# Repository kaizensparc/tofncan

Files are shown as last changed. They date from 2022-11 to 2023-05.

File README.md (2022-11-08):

# tofncan

## Directory Outline
- [`~/pcb/`](pcb) PCB project.
    - [`~/pcb/.kibot`](pcb/.kibot) KiBot configuration files.
    - [`~/pcb/3d_models`](pcb/3d_models) .STEP and .WRL model files for all project specific footprints.
    - [`~/pcb/datasheets`](pcb/datasheets) Data sheets for components used.
    - [`~/pcb/lib_fp.pretty`](pcb/lib_fp.pretty) Project specific footprint library.
    - [`~/pcb/kicad_project`](pcb/kicad_project) Kicad project. When starting a new KiCAD project in this directory, be sure to uncheck *Create a new directory for the project* in the **Create New Project** window.
    - [`~/pcb/lib_sch`](pcb/lib_sch) Project specific schematic symbol libraries.
        - [`~/pcb/lib_sch/lib.lib`](pcb/lib_sch/lib.lib) Project specific schematic symbol library.
    - [`~/pcb/page_layouts`](pcb/page_layouts) Page layouts for pdf outputs.
    - [`~/pcb/outputs`](pcb/outputs) Project output files generated by KiCad and/or KiBot (these are not kept under version control).
        - [`~/pcb/outputs/3d_models`](pcb/outputs/3d_models) Exported 3D models of the board.
        - [`~/pcb/outputs/assembly`](pcb/outputs/assembly) Exported assembly files.
        - [`~/pcb/outputs/bom`](pcb/outputs/bom) Exported BOM files.
        - [`~/pcb/outputs/fabrication`](pcb/outputs/fabrication) Exported production (gerber) files.
        - [`~/pcb/outputs/images`](pcb/outputs/images) Exported images and 3D board renders.
        - [`~/pcb/outputs/pdf`](pcb/outputs/pdf) Exported schematics, board layouts, dimension drawings.
- [`~/firmware/`](firmware) Firmware souce code and binaries.
- [`~/enclosure/`](enclosure) Mechanical CAD design files for the encloser or box. Create seperate directories for `.stl` or other files for 3d printing for easy accesss.

## Managing Schematic Libraries
Project specific symbols can be saved in [`~/pcb/lib_sch/lib.lib`](pcb/lib_sch/lib.lib). Link this library as a project specific library to the project **using a relative path** like `${KIPRJMOD}/../lib_sch/lib.lib`.

### Saving a copy of the global symbols.
The global symbols are pulled from Github when the repository is cloned, and this can cause problems if the global symbols have changed in the meantime. To prevent this, KiCad automatically creates a backup in the project folder of the symbols currently in use named `<<PROJECT NAME>>-cache.lib`. 

To make sure everyone uses the same, you can convert the backup of the symbol library to a symbol library. To do this you need to move this file to  [`~/pcb/lib_sch`](pcb/lib_sch) and rename it to `<<PROJECT NAME>>.lib`. After this, you can add this symbol library as a project-specific symbol library and replace all symbols with the symbols from this library. **NOTE: Do this only after you've completed your whole schematic design!**

## Managing Footprints
Project specific footprints can be saved in [`~/pcb/lib_fp/lib_fp.pretty`](pcb/lib_fp/lib_fp.pretty). Link this library as a project specific library to the project **using a relative path** like `${KIPRJMOD}/../lib_fp/lib_fp.pretty`. Global symbols that are used can be copied to this folder and replaced with this local variant. 

## Managing 3D models of components
3D models for project specific components should be saved in [`~/pcb/3d_models`](pcb/3d_models). Then they can be linked to the matching footprint **using a relative path** like `${KIPRJMOD}/../3d_models/filename.step`.

## Managing the BOM information
Add the following field name templates in Eeschema (`preferences >> Preferences... >> Field Name Templates`):

| Name | Visible | URL | _Description_ |
|:--- | :---: | :---: | :--- |
| `MFN` | :white_check_mark: | :white_large_square: | _Manufacturer name._ |
| `MFP` | :white_check_mark: | :white_large_square: | _Manufacturer product number._ |
| `LCSC#`  | :white_check_mark: | :white_large_square: | _LCSC/JLCPCB part number (leave part number empty if not using JLCPCB assembly)._ |
| `Config` | :white_check_mark: | :white_large_square: | _Board configuration to apply this part to or `DNF` if part should not be fitted on final board._ |

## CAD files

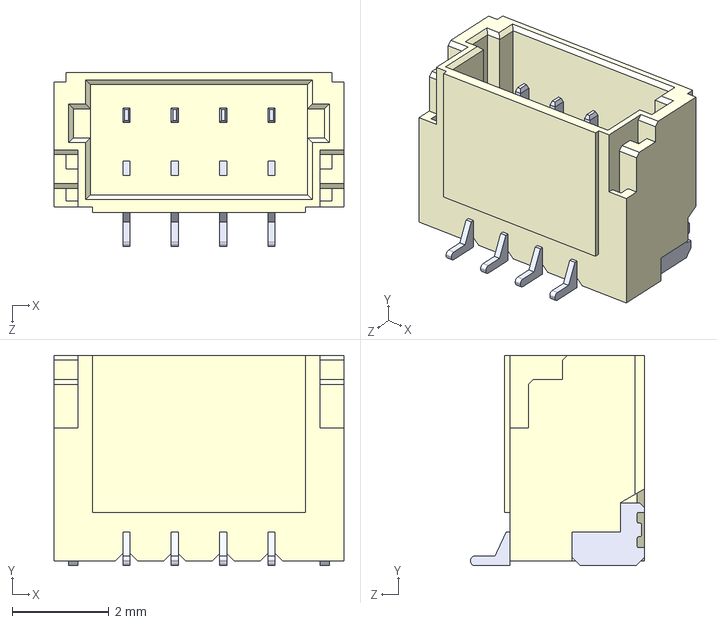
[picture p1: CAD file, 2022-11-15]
pcb/3d_models/BM04B-SRSS-TB-LF-SN.step
6.00 x 4.35 x 3.60 mm

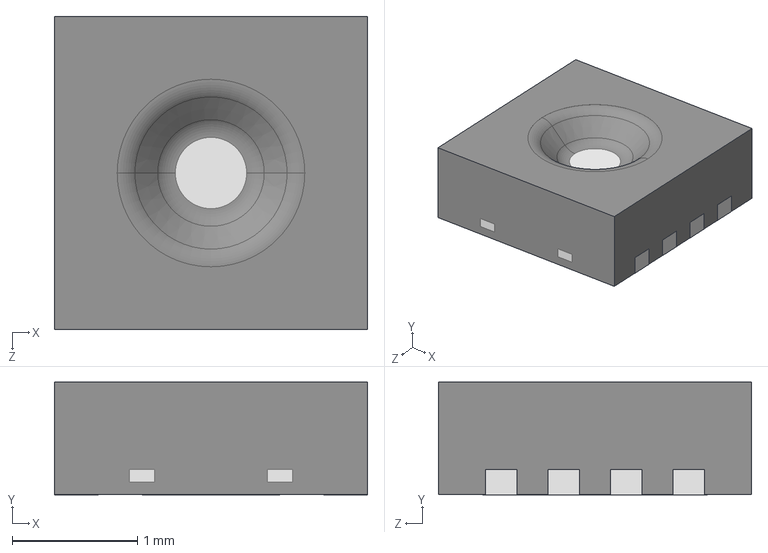
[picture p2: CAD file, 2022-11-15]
pcb/3d_models/SHT30-DIS-B.step
2.50 x 0.901 x 2.50 mm

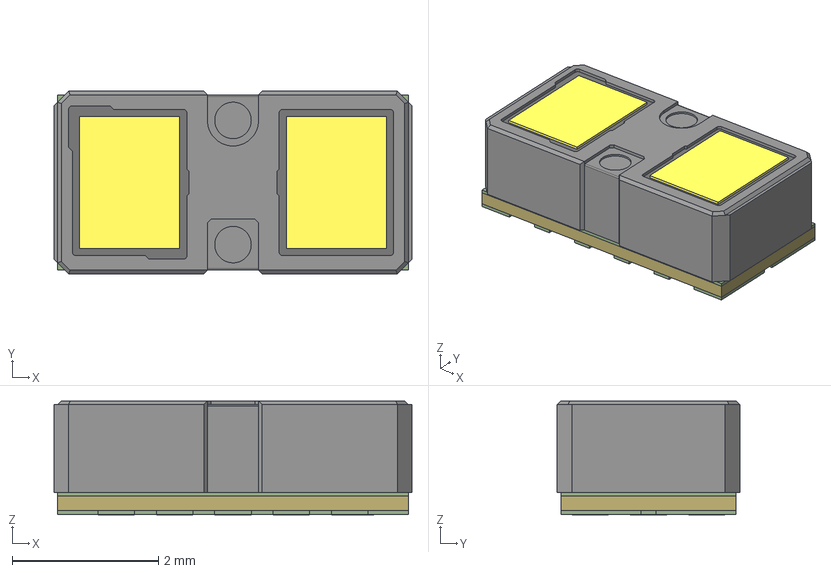
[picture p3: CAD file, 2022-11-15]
pcb/3d_models/vl53l1x.step
4.90 x 2.50 x 1.56 mm
pcb
kork
pads
blend
lens
main
blocker

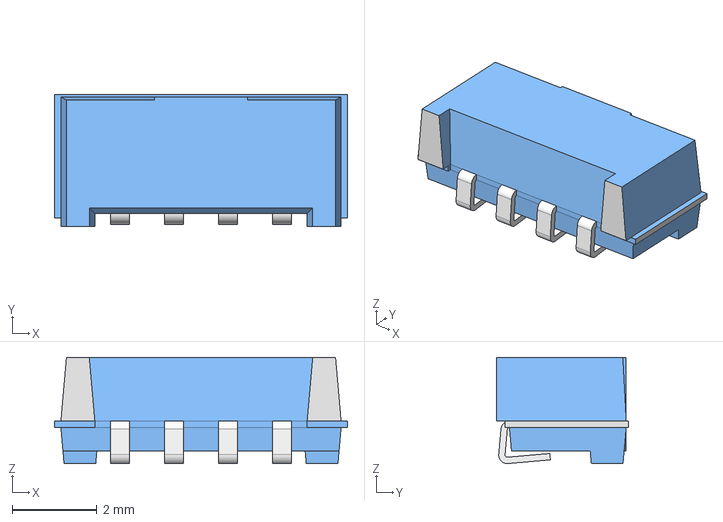
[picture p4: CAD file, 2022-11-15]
pcb/3d_models/84592VEML7700.stp
6.90 x 3.10 x 2.50 mm

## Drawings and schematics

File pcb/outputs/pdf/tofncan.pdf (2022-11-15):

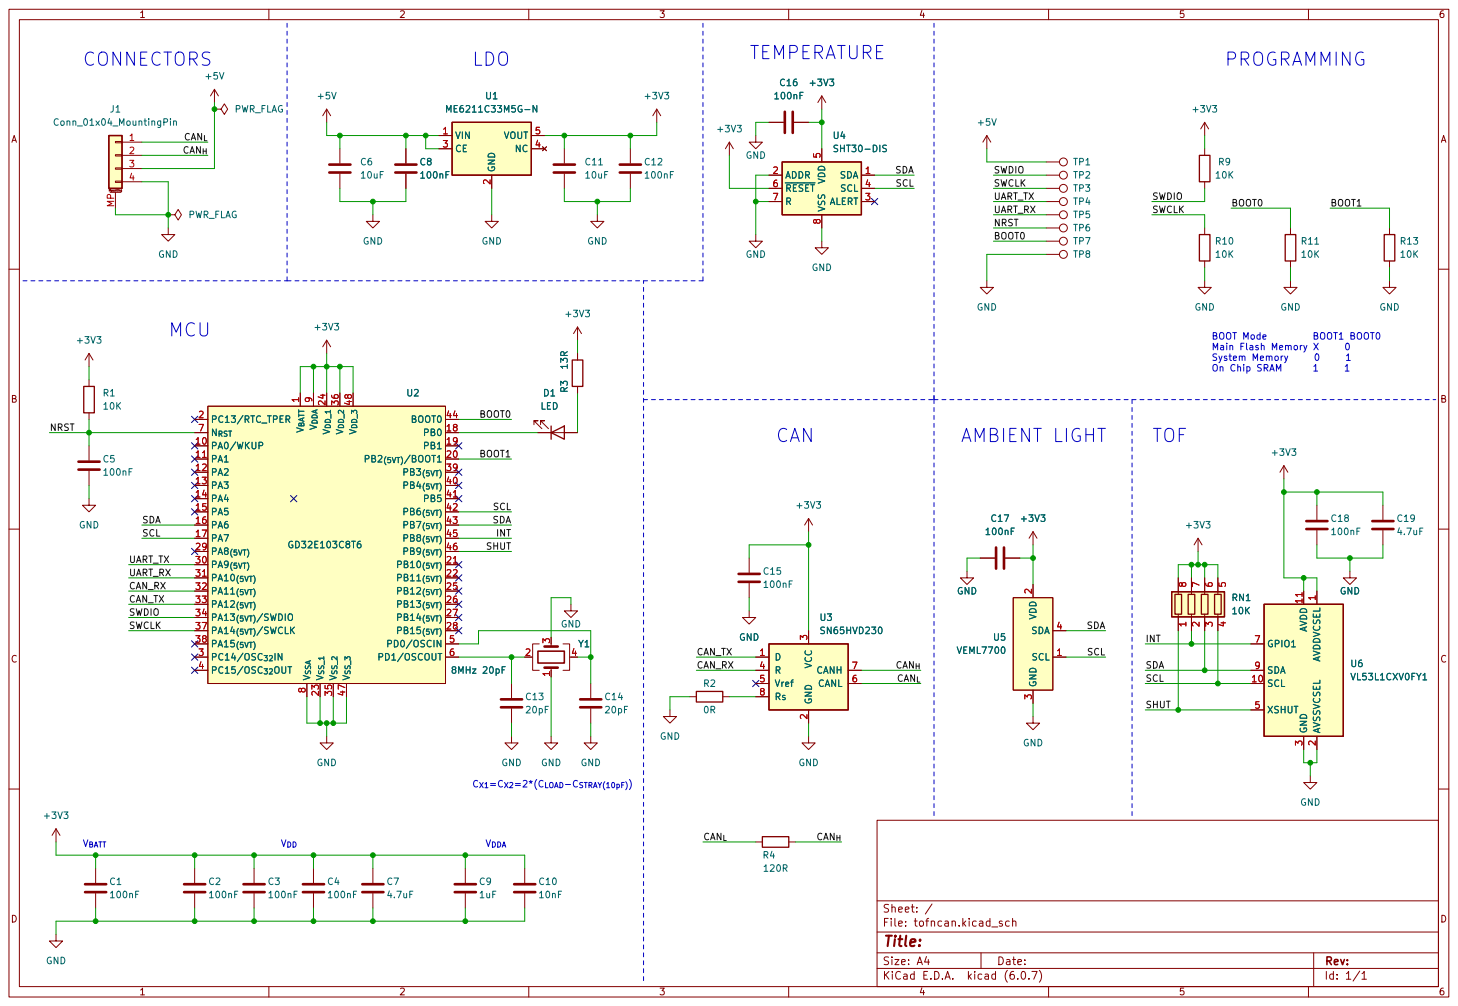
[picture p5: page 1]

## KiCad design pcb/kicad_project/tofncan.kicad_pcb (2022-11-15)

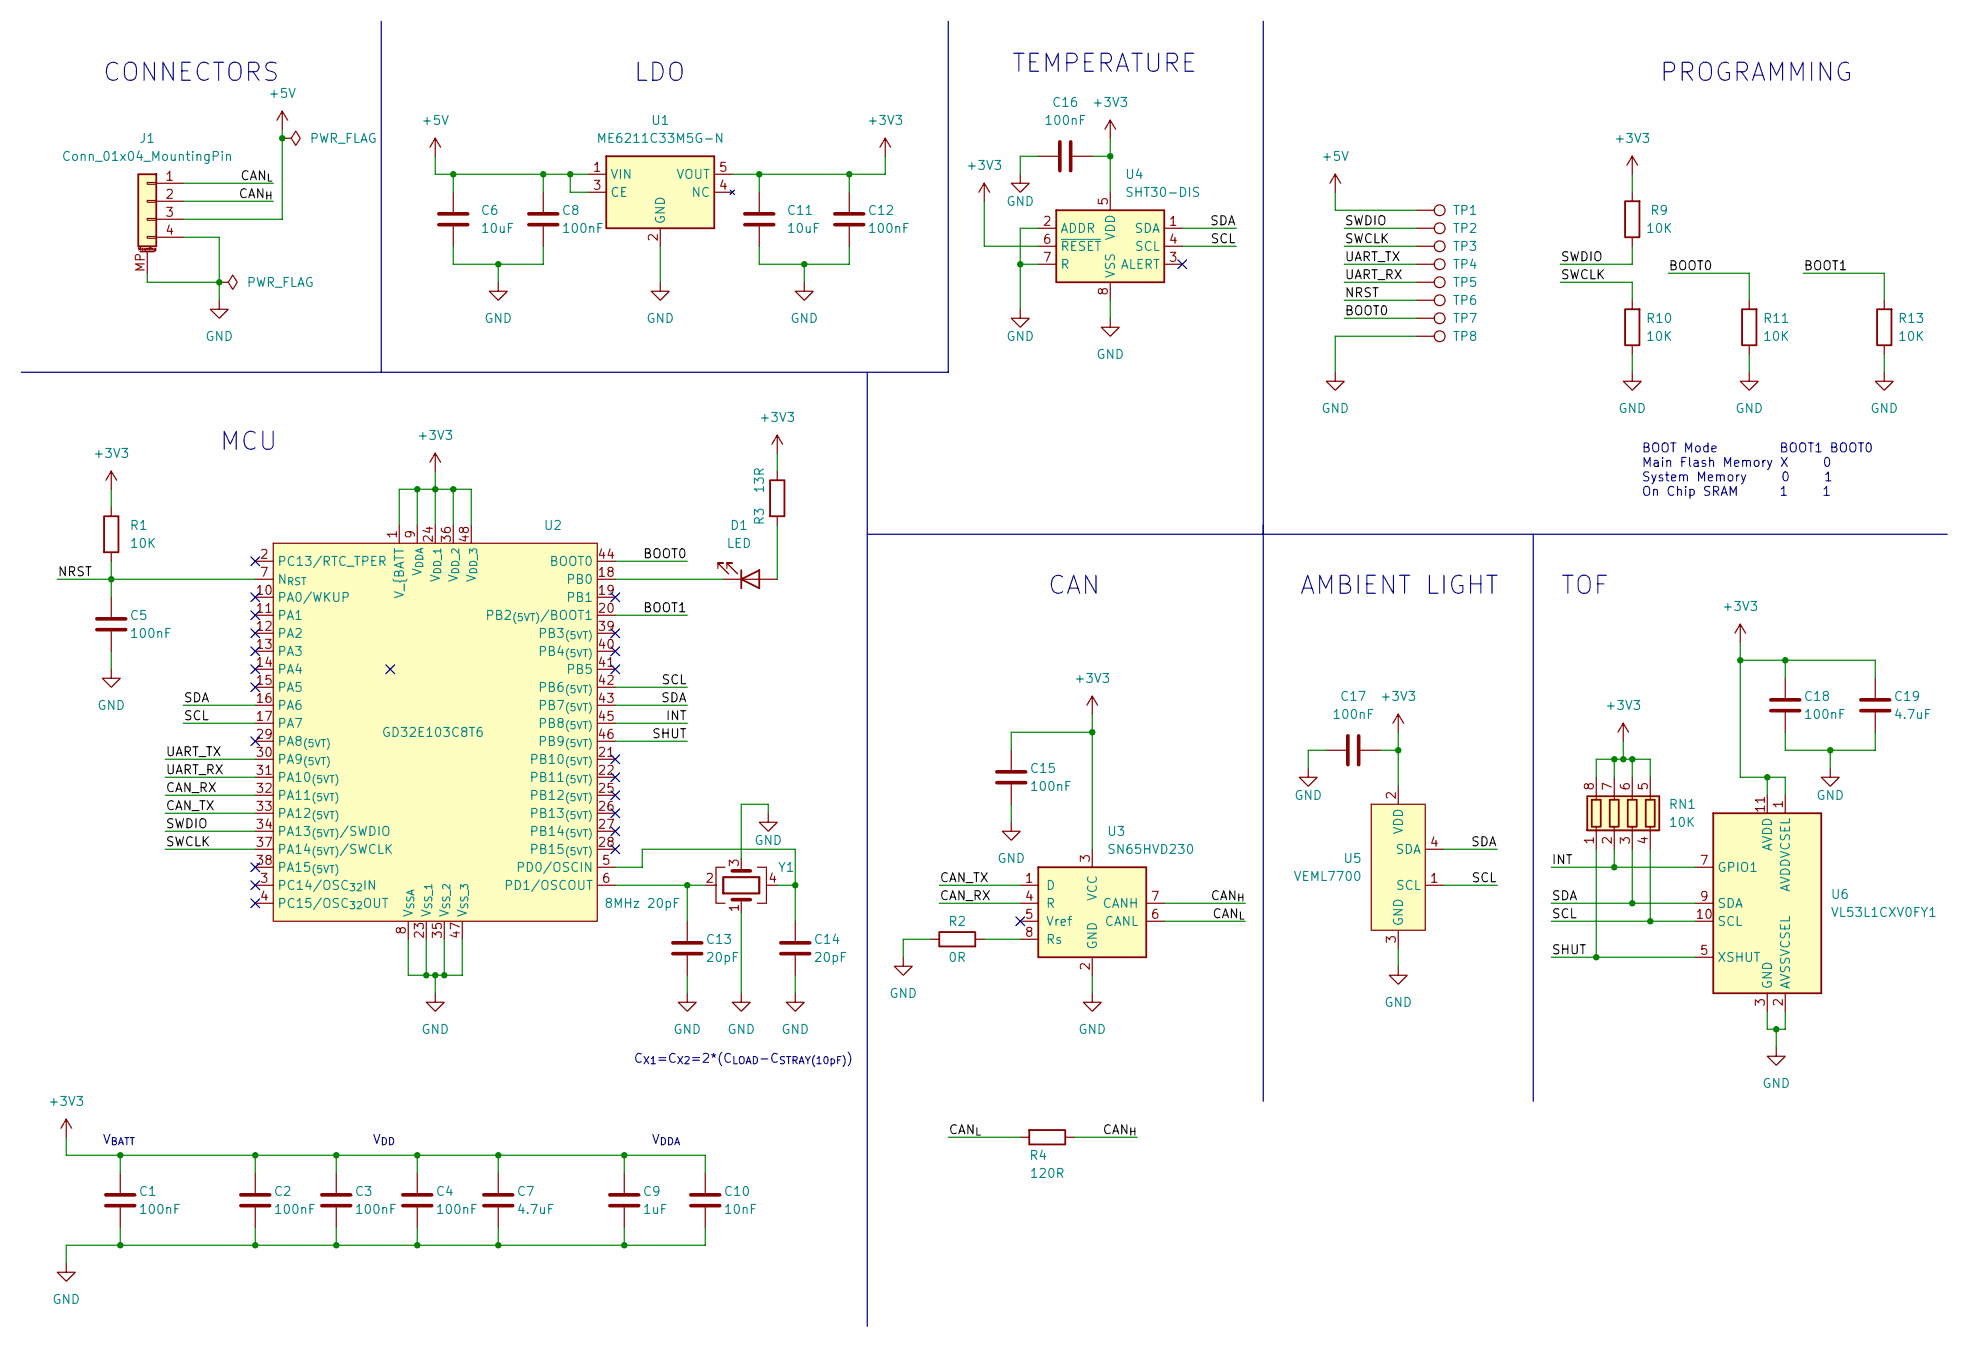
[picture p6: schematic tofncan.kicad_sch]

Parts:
C1, C2, C3, C4, C5, C8, C12, C15, C16, C17, C18: 100nF; C_0402_1005Metric; LCSC C1525
C6, C11: 10uF; C_0805_2012Metric; LCSC C88484
C7, C19: 4.7uF; C_0402_1005Metric; LCSC C23733
C9: 1uF; C_0402_1005Metric; LCSC C52923
C10: 10nF; C_0402_1005Metric; LCSC C400948
C13, C14: 20pF; C_0402_1005Metric; LCSC C76959
D1: LED; LED_0603_1608Metric; LCSC C965809
J1: Conn_01x04_MountingPin; JST_SH_BM04B-SRSS-TB_1x04-1MP_P1.00mm_Vertical; LCSC C160390
R1, R9, R10, R11, R13: 10K; R_0402_1005Metric; LCSC C60490
R2: 0R; R_0402_1005Metric; LCSC C106231
R3: 13R; R_0402_1005Metric; LCSC C412909
R4: 120R; R_0402_1005Metric; LCSC C114758
RN1: 10K; R_Array_Convex_4x0402; LCSC C326872
TP1, TP2, TP3, TP4, TP5, TP6, TP7, TP8: TestPoint; TestPoint_Pad_D1.0mm
U1: ME6211C33M5G-N; SOT-23-5; LCSC C82942
U2: GD32E103C8T6; LQFP-48_7x7mm_P0.5mm; LCSC C350804
U3: SN65HVD230; SOIC-8_3.9x4.9mm_P1.27mm; LCSC C12084
U4: SHT30-DIS; Sensirion_DFN-8-1EP_2.5x2.5mm_P0.5mm_EP1.1x1.7mm; LCSC C77361
U5: VEML7700; VEML7700-TOP; LCSC C504893
U6: VL53L1CXV0FY1; ST_VL53L1X; LCSC C190004
Y1: 8MHz 20pF; Crystal_SMD_3225-4Pin_3.2x2.5mm; LCSC C720915

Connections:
+3V3: C1.1, C2.1, C3.1, C4.1, C7.1, C9.1, C10.1, C11.1, C12.1, C15.1, C16.2, C17.2, C18.1, C19.1, R1.1, R3.1, R9.2, RN1.5 (R4.2), RN1.6 (R3.2), RN1.7 (R2.2), RN1.8 (R1.2), U1.5 (VOUT), U2.1 (V_{BATT), U2.9 (V_{DDA}), U2.24 (V_{DD_1}), U2.36 (V_{DD_2}), U2.48 (V_{DD_3}), U3.3 (VCC), U4.5 (VDD), U4.6 (~RESET), U5.2 (VDD), U6.1 (AVDDVCSEL), U6.11 (AVDD)
+5V: C6.1, C8.1, J1.3, TP1.1, U1.1 (VIN), U1.3 (CE)
/BOOT0: R11.2, TP7.1, U2.44 (BOOT0)
/BOOT1: R13.2, U2.20 (PB2_{(5VT)}/BOOT1)
/CAN_RX: U2.32 (PA11_{(5VT)}), U3.4 (R)
/CAN_TX: U2.33 (PA12_{(5VT)}), U3.1 (D)
/CAN_{H}: J1.2, R4.1, U3.7 (CANH)
/CAN_{L}: J1.1, R4.2, U3.6 (CANL)
/INT: RN1.2 (R2.1), U2.45 (PB8_{(5VT)}), U6.7 (GPIO1)
/NRST: C5.1, R1.2, TP6.1, U2.7 (N_{RST})
/SCL: RN1.4 (R4.1), U2.17 (PA7), U2.42 (PB6_{(5VT)}), U4.4 (SCL), U5.1 (SCL), U6.10 (SCL)
/SDA: RN1.3 (R3.1), U2.16 (PA6), U2.43 (PB7_{(5VT)}), U4.1 (SDA), U5.4 (SDA), U6.9 (SDA)
/SHUT: RN1.1 (R1.1), U2.46 (PB9_{(5VT)}), U6.5 (XSHUT)
/SWCLK: R10.2, TP3.1, U2.37 (PA14_{(5VT)}/SWCLK)
/SWDIO: R9.1, TP2.1, U2.34 (PA13_{(5VT)}/SWDIO)
/UART_RX: TP5.1, U2.31 (PA10_{(5VT)})
/UART_TX: TP4.1, U2.30 (PA9_{(5VT)})
GND: C1.2, C2.2, C3.2, C4.2, C5.2, C6.2, C7.2, C8.2, C9.2, C10.2, C11.2, C12.2, C13.2, C14.2, C15.2, C16.1, C17.1, C18.2, C19.2, J1.4, J1.MP (MountPin), R2.1, R10.1, R11.1, R13.1, TP8.1, U1.2 (GND), U2.8 (V_{SSA}), U2.23 (V_{SS_1}), U2.35 (V_{SS_2}), U2.47 (V_{SS_3}), U3.2 (GND), U4.2 (ADDR), U4.7 (R), U4.8 (VSS), U4.9 (VSS), U5.3 (GND), U6.2 (AVSSVCSEL), U6.3 (GND), U6.4 (GND), U6.6 (GND), U6.12 (GND), Y1.1, Y1.3
unnamed: C13.1, U2.6 (PD1/OSCOUT), Y1.2
unnamed: C14.1, U2.5 (PD0/OSCIN), Y1.4
unnamed: D1.1 (K), U2.18 (PB0)
unnamed: D1.2 (A), R3.2
unnamed: R2.2, U3.8 (Rs)

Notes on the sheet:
BOOT Mode BOOT1 BOOT0 Main Flash Memory X 0 System Memory 0 1 On Chip SRAM 1 1
C_{X1}=C_{X2}=2*(C_{LOAD}-C_{STRAY(10pF)})
CONNECTORS
TOF
V_{DD}
V_{DDA}
PROGRAMMING
AMBIENT LIGHT
MCU
TEMPERATURE
V_{BATT}
LDO
CAN

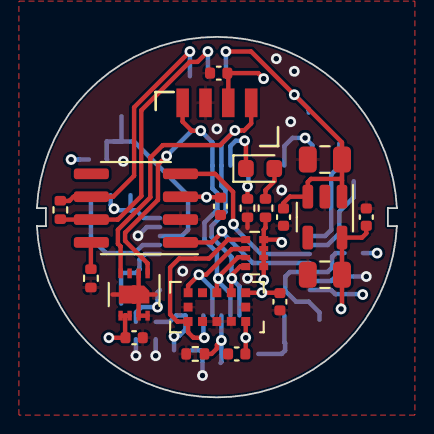
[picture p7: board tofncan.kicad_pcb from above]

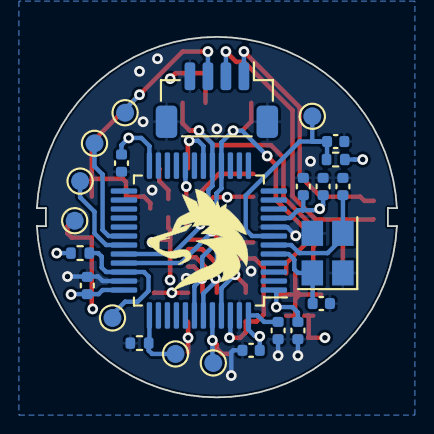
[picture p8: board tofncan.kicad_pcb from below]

Board: 4 copper layers, 20.0 x 20.0 mm, 45 parts (24 on the bottom side), 23 nets.

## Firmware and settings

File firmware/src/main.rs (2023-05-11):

//! Welcome to ToFnCAN firmware documentation!
//!
//! # CAN bus communication
//!
//! ## Frame IDs
//!
//! Note: all CAN addresses below are offset by [`FRAME_ID_BASE`] unless for firmware
//! which is at address 1 (maximum priority) [TODO]
//!
//! The bus addressing for this node is the following:
//!
//! - 0 (emitter): Welcome message, sent at boot only
//! - 1 (receiver): system configuration registers
//! - 2 (receiver): TOF general configuration registers
//! - 3 (receiver): TOF timing registers
//! - 4 (emitter): SHT30 results
//! - 5 (emitter): VEML results
//! - 6 (emitter): VL53 rates readings
//! - 7 (emitter): VL53 effective SPAD, sigma and range readings
//! - 8 (emitter): VL53 stream count and range status
//!
//! ## Messages
//!
//! All messages are send in network order (Big Endian)
//!
//! ### Welcome message
//!
//! - Boot reason (4 bytes)
//!
//! ### System configuration registers
//!
//! - restart (1 byte)
//! - automatic retransmit (1 byte)
//! - diffusion interval (ms, 4 bytes)
//!
//! ### ToF general configuration registers
//!
//! - [distance mode](`vl53l1::DistanceMode`) (1 byte)
//! - roi (bot_right_x, bot_right_y, top_left_x, top_left_y, 4 bytes total)
//!
//! ### ToF timing registers
//!
//! - measurement timing budget (us, 4 bytes)
//! - inter measurement period (ms, 4 bytes)
//!
//! ### SHT30 Results
//!
//! - Status (2 bytes)
//! - Humidity (2 bytes)
//! - Temperature (4 bytes)
//!
//! ### VEML Results
//!
//! - White (2 bytes)
//! - Lux (4 bytes)
//!
//! ### VL53
//!
//! #### Rates readings
//!
//! - Signal rate (MCPS 16.16 fix point value)
//! - Ambient rate (MCPS 16.16 fix point value)
//!
//! #### Effective SPAD, sigma and range readings
//!
//! - Effective SPAD count (2 bytes, real value is /256)
//! - Sigma value in mm (16.16 fix point value)
//! - Range distance in mm (2 bytes)
//!
//! #### Stream count and range status
//!
//! - Stream count (1 byte)
//! - [Range status](`vl53l1::RangeStatus`) (1 byte)
//!

#![deny(unsafe_code)]
#![no_std]
#![no_main]

use panic_reset as _;

use rtt_target::{rprint, rprintln, rtt_init_print};

use cortex_m_rt::entry;
use gd32e103_hal::{can, delay::Delay, i2c, pac, prelude::*, timer, watchdog};
use sht3x::Sht3x;
use veml7700::Veml7700;

/// Using 11bit CAN addressing, please do not go after 0x7FF - 5
pub const FRAME_ID_BASE: u16 = 0x20;

#[repr(u16)]
pub enum FrameIds {
    Welcome = FRAME_ID_BASE,
    SystemConfiguration = FRAME_ID_BASE + 1,
    ToFGeneralConfiguration = FRAME_ID_BASE + 2,
    ToFTiming = FRAME_ID_BASE + 3,
    Sht30 = FRAME_ID_BASE + 4,
    Veml = FRAME_ID_BASE + 5,
    ToFRates = FRAME_ID_BASE + 6,
    ToFSPAD = FRAME_ID_BASE + 7,
    ToFStream = FRAME_ID_BASE + 8,
}

fn send_welcome<I>(can_bus: &mut bxcan::Can<I>, boot_reason: u32)
where
    I: bxcan::Instance,
{
    rprint!("Sending welcome... ");
    let frame = bxcan::Frame::new_data(
        bxcan::StandardId::new(FrameIds::Welcome as u16).unwrap(),
        boot_reason.to_be_bytes(),
    );
    can_bus.transmit(&frame).unwrap();
    while !can_bus.is_transmitter_idle() {}
    rprintln!("Done.");
}

fn parse_can_msg<I, T>(
    frame: &bxcan::Frame,
    can_bus: &mut bxcan::Can<I>,
    cdt: &mut T,
    tof: &mut vl53l1::Device,
) where
    I: bxcan::Instance,
    T: embedded_hal::timer::CountDown,
    T::Time: From<gd32e103_hal::time::Hertz>,
{
    let id = {
        match frame.id() {
            bxcan::Id::Standard(x) => x.as_raw(),
            bxcan::Id::Extended(_) => return,
        }
    };

    let data = match frame.data() {
        Some(x) => x,
        None => return,
    };

    if id == FrameIds::SystemConfiguration as u16 {
        if data.len() != 6 {
            return;
        }
        if data[0] != 0 {
            cortex_m::peripheral::SCB::sys_reset();
        }
        can_bus
            .modify_config()
            .set_automatic_retransmit(data[1] != 0)
            .enable();
        let t_ms = u32::from_be_bytes(data[2..5].try_into().unwrap());
        cdt.start((1000 / t_ms).hz());
    } else if id == FrameIds::ToFGeneralConfiguration as u16 {
        if data.len() != 5 {
            return;
        }
        let distance_mode = match data[0] {
            1 => vl53l1::DistanceMode::Short,
            2 => vl53l1::DistanceMode::Medium,
            3 => vl53l1::DistanceMode::Long,
            _ => return,
        };
        vl53l1::set_distance_mode(tof, distance_mode).unwrap();
        let roi = vl53l1::UserRoi {
            bot_right_x: data[1],
            bot_right_y: data[2],
            top_left_x: data[3],
            top_left_y: data[4],
        };
        vl53l1::set_user_roi(tof, roi).unwrap();
    } else if id == FrameIds::ToFTiming as u16 {
        if data.len() != 8 {
            return;
        }
        vl53l1::set_measurement_timing_budget_micro_seconds(
            tof,
            u32::from_be_bytes(data[..3].try_into().unwrap()),
        )
        .unwrap();
        vl53l1::set_inter_measurement_period_milli_seconds(
            tof,
            u32::from_be_bytes(data[4..7].try_into().unwrap()),
        )
        .unwrap();
    }
}

fn wait_for_system_config<I, T>(
    can_bus: &mut bxcan::Can<I>,
    wdt: &mut watchdog::FreeWatchdog,
    delay: &mut Delay,
    cdt: &mut T,
    tof: &mut vl53l1::Device,
) where
    I: bxcan::Instance,
    T: embedded_hal::timer::CountDown,
    T::Time: From<gd32e103_hal::time::Hertz>,
{
    rprint!("Waiting for configuration... ");
    let mut iter = 0u32;
    loop {
        wdt.feed();
        match can_bus.receive() {
            Ok(rx) => {
                parse_can_msg(&rx, can_bus, cdt, tof);
                if rx.id()
                    == bxcan::Id::Standard(
                        bxcan::StandardId::new(FrameIds::SystemConfiguration as u16).unwrap(),
                    )
                {
                    rprint!("{:?}", rx.data());
                    break;
                }
            }
            Err(nb::Error::Other(_)) => rprint!("Overrun error"),
            Err(nb::Error::WouldBlock) => {}
        };
        iter = iter.saturating_add(1);
        if iter > 1000 {
            rprint!("No configuration received, using defaults...");
            break;
        }
        delay.delay_ms(5u32);
    }
    rprintln!("Done.");
}

fn read_sht30<I2C, E>(sht30: &mut sht3x::Sht3x<I2C>, delay: &mut Delay) -> bxcan::Frame
where
    I2C: embedded_hal::blocking::i2c::Read<Error = E>
        + embedded_hal::blocking::i2c::Write<Error = E>
        + embedded_hal::blocking::i2c::WriteRead<Error = E>,
    E: core::fmt::Debug,
{
    let sht30_status = sht30.status(delay).unwrap().bits();
    let sht30_readings = sht30
        .measure(
            sht3x::ClockStretch::Enabled,
            sht3x::Repeatability::Medium,
            delay,
        )
        .unwrap();

    bxcan::Frame::new_data(
        bxcan::StandardId::new(FrameIds::Sht30 as u16).unwrap(),
        [
            sht30_status.to_be_bytes()[0],
            sht30_status.to_be_bytes()[1],
            sht30_readings.humidity.to_be_bytes()[0],
            sht30_readings.humidity.to_be_bytes()[1],
            sht30_readings.temperature.to_be_bytes()[0],
            sht30_readings.temperature.to_be_bytes()[1],
            sht30_readings.temperature.to_be_bytes()[2],
            sht30_readings.temperature.to_be_bytes()[3],
        ],
    )
}

fn read_veml<I2C, E>(veml: &mut Veml7700<I2C>) -> bxcan::Frame
where
    I2C: embedded_hal::blocking::i2c::Read<Error = E>
        + embedded_hal::blocking::i2c::Write<Error = E>
        + embedded_hal::blocking::i2c::WriteRead<Error = E>,
    E: core::fmt::Debug,
{
    let veml_white = veml.read_white().unwrap();
    let veml_lux = veml.read_lux().unwrap();
    bxcan::Frame::new_data(
        bxcan::StandardId::new(FrameIds::Veml as u16).unwrap(),
        [
            veml_white.to_be_bytes()[0],
            veml_white.to_be_bytes()[1],
            veml_lux.to_be_bytes()[0],
            veml_lux.to_be_bytes()[1],
            veml_lux.to_be_bytes()[2],
            veml_lux.to_be_bytes()[3],
        ],
    )
}

fn read_send_vl53<I, I2C, E>(
    tof: &mut vl53l1::Device,
    tof_i2c: &mut I2C,
    delay: &mut Delay,
    can_bus: &mut bxcan::Can<I>,
) where
    I: bxcan::Instance,
    I2C: embedded_hal::blocking::i2c::Read<Error = E>
        + embedded_hal::blocking::i2c::Write<Error = E>
        + embedded_hal::blocking::i2c::WriteRead<Error = E>,
    E: core::fmt::Debug,
{
    let vl53_readings = {
        vl53l1::wait_measurement_data_ready(tof, tof_i2c, delay).unwrap();
        let r = vl53l1::get_ranging_measurement_data(tof, tof_i2c).unwrap();
        vl53l1::clear_interrupt_and_start_measurement(tof, tof_i2c, delay).unwrap();
        r
    };
    let frame = bxcan::Frame::new_data(
        bxcan::StandardId::new(FrameIds::ToFRates as u16).unwrap(),
        [
            vl53_readings.signal_rate_rtn_mega_cps.to_be_bytes()[0],
            vl53_readings.signal_rate_rtn_mega_cps.to_be_bytes()[1],
            vl53_readings.signal_rate_rtn_mega_cps.to_be_bytes()[2],
            vl53_readings.signal_rate_rtn_mega_cps.to_be_bytes()[3],
            vl53_readings.ambient_rate_rtn_mega_cps.to_be_bytes()[0],
            vl53_readings.ambient_rate_rtn_mega_cps.to_be_bytes()[1],
            vl53_readings.ambient_rate_rtn_mega_cps.to_be_bytes()[2],
            vl53_readings.ambient_rate_rtn_mega_cps.to_be_bytes()[3],
        ],
    );
    while !can_bus.is_transmitter_idle() {}
    can_bus.transmit(&frame).unwrap();

    let frame = bxcan::Frame::new_data(
        bxcan::StandardId::new(FrameIds::ToFSPAD as u16).unwrap(),
        [
            vl53_readings.effective_spad_rtn_count.to_be_bytes()[0],
            vl53_readings.effective_spad_rtn_count.to_be_bytes()[1],
            vl53_readings.sigma_milli_meter.to_be_bytes()[0],
            vl53_readings.sigma_milli_meter.to_be_bytes()[1],
            vl53_readings.sigma_milli_meter.to_be_bytes()[2],
            vl53_readings.sigma_milli_meter.to_be_bytes()[3],
            vl53_readings.range_milli_meter.to_be_bytes()[0],
            vl53_readings.range_milli_meter.to_be_bytes()[1],
        ],
    );
    while !can_bus.is_transmitter_idle() {}
    can_bus.transmit(&frame).unwrap();

    let frame = bxcan::Frame::new_data(
        bxcan::StandardId::new(FrameIds::ToFStream as u16).unwrap(),
        [vl53_readings.stream_count, vl53_readings.range_status as u8],
    );
    while !can_bus.is_transmitter_idle() {}
    can_bus.transmit(&frame).unwrap();
}

fn check_incoming<I, T>(can_bus: &mut bxcan::Can<I>, cdt: &mut T, tof: &mut vl53l1::Device)
where
    I: bxcan::Instance,
    T: embedded_hal::timer::CountDown,
    T::Time: From<gd32e103_hal::time::Hertz>,
{
    loop {
        match can_bus.rx0().receive() {
            Ok(rx) => parse_can_msg(&rx, can_bus, cdt, tof),
            Err(nb::Error::Other(_)) => rprint!("Overrun error"),
            Err(nb::Error::WouldBlock) => break,
        };
    }
}

#[entry]
fn main() -> ! {
    rtt_init_print!();
    rprintln!("TOFnCAN loading...");

    // Get access to the core peripherals from the cortex-m crate
    let mut cp = cortex_m::Peripherals::take().unwrap();
    // Get access to the device specific peripherals from the peripheral access crate
    let mut dp = pac::Peripherals::take().unwrap();

    // Take ownership over the raw rcu and flash devices and convert them into the corresponding HAL
    // structs.
    let mut flash = dp.FMC.constrain();
    let mut rcu = dp.RCU.constrain();

    // Get reset reason
    let reason = rcu.rstsck.reason();
    rprintln!("Reset reason: {}", reason);

    // Freeze the configuration of all the clocks in the system and store the frozen frequencies.
    rprint!("Initializing clocks... ");
    let clocks = rcu
        .cfgr
        .use_hxtal(8.mhz())
        .sysclk(8.mhz())
        .hclk(8.mhz())
        .pclk1(8.mhz())
        .freeze(&mut flash.ws);
    rprintln!("Done.");

    // Initialize the watchdog timer
    let mut wdt = watchdog::FreeWatchdog::new(dp.FWDGT);
    wdt.start(5000.ms());
    wdt.feed();

    // Acquire the GPIO peripherals
    rprint!("Initializing internal peripherals... ");
    let mut gpioa = dp.GPIOA.split(&mut rcu.apb2);
    let mut gpiob = dp.GPIOB.split(&mut rcu.apb2);

    // Configure gpio B pin 0 as a push-pull output. The `crl` register is passed to the function
    // in order to configure the port. For pins 8+, crh should be passed instead.
    // let mut led = gpiob.pb0.into_push_pull_output(&mut gpiob.crl);

    // Configure the syst timer
    let mut delay = Delay::new(cp.SYST, &clocks);

    let sda = gpiob.pb7.into_alternate_open_drain(&mut gpiob.crl);
    let scl = gpiob.pb6.into_alternate_open_drain(&mut gpiob.crl);

    cp.DWT.enable_cycle_counter();
    let i2c_dev = i2c::BlockingI2c::i2c0(
        dp.I2C0,
        scl,
        sda,
        i2c::Mode::standard(40.khz()),
        &clocks,
        &mut rcu.apb1,
        1000,
        3,
        1000,
        1000,
    );
    rprintln!("Done.");

    let bus = shared_bus::BusManagerSimple::new(i2c_dev);

    rprint!("Initializing SHT30 sensor... ");
    wdt.feed();
    let mut sht30 = Sht3x::new(bus.acquire_i2c(), sht3x::Address::Low);
    let _ = sht30.reset(&mut delay).unwrap();
    let _ = sht30.status(&mut delay).unwrap();
    rprintln!("Done.");

    rprint!("Initializing VEML7700 sensor... ");
    wdt.feed();
    let mut veml = Veml7700::new(bus.acquire_i2c());
    veml.enable().unwrap();
    rprintln!("Done.");

    rprint!("Initializing VL53L1 sensor... ");
    wdt.feed();
    let mut tof = vl53l1::Device::default();
    let mut tof_i2c = bus.acquire_i2c();
    vl53l1::software_reset(&mut tof, &mut tof_i2c, &mut delay).unwrap();

    vl53l1::data_init(&mut tof, &mut tof_i2c).unwrap();
    vl53l1::static_init(&mut tof).unwrap();

    let roi = vl53l1::UserRoi {
        bot_right_x: 10,
        bot_right_y: 6,
        top_left_x: 6,
        top_left_y: 10,
    };
    vl53l1::set_user_roi(&mut tof, roi).unwrap();
    vl53l1::set_distance_mode(&mut tof, vl53l1::DistanceMode::Medium).unwrap();
    vl53l1::set_measurement_timing_budget_micro_seconds(&mut tof, 50_000).unwrap();
    vl53l1::set_inter_measurement_period_milli_seconds(&mut tof, 60).unwrap();

    vl53l1::clear_interrupt_and_start_measurement(&mut tof, &mut tof_i2c, &mut delay).unwrap();
    vl53l1::wait_measurement_data_ready(&mut tof, &mut tof_i2c, &mut delay).unwrap();
    vl53l1::get_ranging_measurement_data(&mut tof, &mut tof_i2c).unwrap();
    rprintln!("Done.");

    rprint!("Initializing CAN bus... ");
    wdt.feed();
    let pa12 = gpioa.pa12.into_alternate_push_pull(&mut gpioa.crh);
    let pa11 = gpioa.pa11.into_floating_input(&mut gpioa.crh);
    let can_bus = can::Can::new(dp.CAN0, &mut rcu.apb1);
    can_bus.assign_pins((pa12, pa11), &mut dp.AFIO);
    // Bit timing is defined via http://www.bittiming.can-wiki.info/?CLK=8&ctype=bxCAN&calc=1
    let mut can_bus = bxcan::Can::builder(can_bus)
        .set_automatic_retransmit(true)
        .set_bit_timing(0x001c0001)
        .enable();
    can_bus
        .modify_filters()
        .clear()
        .enable_bank(
            0,
            bxcan::Fifo::Fifo0,
            bxcan::filter::Mask32::frames_with_std_id(
                bxcan::StandardId::new(1u16).unwrap(),
                bxcan::StandardId::MAX,
            ),
        )
        .enable_bank(
            1,
            bxcan::Fifo::Fifo0,
            bxcan::filter::Mask32::frames_with_std_id(
                bxcan::StandardId::new(FrameIds::SystemConfiguration as u16).unwrap(),
                bxcan::StandardId::MAX,
            ),
        )
        .enable_bank(
            2,
            bxcan::Fifo::Fifo0,
            bxcan::filter::Mask32::frames_with_std_id(
                bxcan::StandardId::new(FrameIds::ToFGeneralConfiguration as u16).unwrap(),
                bxcan::StandardId::MAX,
            ),
        )
        .enable_bank(
            3,
            bxcan::Fifo::Fifo0,
            bxcan::filter::Mask32::frames_with_std_id(
                bxcan::StandardId::new(FrameIds::ToFTiming as u16).unwrap(),
                bxcan::StandardId::MAX,
            ),
        );
    rprintln!("Done.");

    // Initialize the timer used for diffusion intervals
    let mut cdt = timer::Timer::timer0(dp.TIMER0, &clocks, &mut rcu.apb2).start_count_down(1.hz());

    // Send the welcome message and wait for a start/timeout before looping
    wdt.feed();
    send_welcome(&mut can_bus, reason);
    wait_for_system_config(&mut can_bus, &mut wdt, &mut delay, &mut cdt, &mut tof);

    loop {
        if cdt.wait() == Err(nb::Error::WouldBlock) {
            check_incoming(&mut can_bus, &mut cdt, &mut tof);
            wdt.feed();
            continue;
        }

        rprint!("Sending readings... ");
        wdt.feed();

        rprint!("SHT30 ");
        let frame = read_sht30(&mut sht30, &mut delay);
        while !can_bus.is_transmitter_idle() {}
        can_bus.transmit(&frame).unwrap();

        rprint!("| VEML ");
        let frame = read_veml(&mut veml);
        while !can_bus.is_transmitter_idle() {}
        can_bus.transmit(&frame).unwrap();

        rprint!("| VL53 ");
        read_send_vl53(&mut tof, &mut tof_i2c, &mut delay, &mut can_bus);

        // Wait until the end of transmission before continuing
        while !can_bus.is_transmitter_idle() {}

        wdt.feed();
        rprintln!("Done.");
    }
}

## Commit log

2022-11-08 Add kicad skeleton
2022-11-15 Add first version of PCB
    [84592VEML7700.stp, BM04B-SRSS-TB-LF-SN.step, SHT30-DIS-B.step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]
2023-05-10 Add CAN bus layer
